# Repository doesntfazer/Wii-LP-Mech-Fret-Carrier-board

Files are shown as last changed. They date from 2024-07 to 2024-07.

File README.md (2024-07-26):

# Wii-LP-Mech-Fret-Carrier-board
A Wii Les Paul Mech fret PCB for the Frets, and the carrier board. These should be drop in replacements for the fret board and carrier board. Carrier board uses an RP2040 zero.

Frets use Choc V1 switches. I recommend using the pro reds or reds if you want to use the bracket.

Cherry MX switches for the strum. You can use whatever switches you want, But I would recommend using Box switches of some kind that are pretty heavy.

[Get the guitar configurator software here](https://github.com/Santroller/Santroller/releases/tag/v10.1.153)

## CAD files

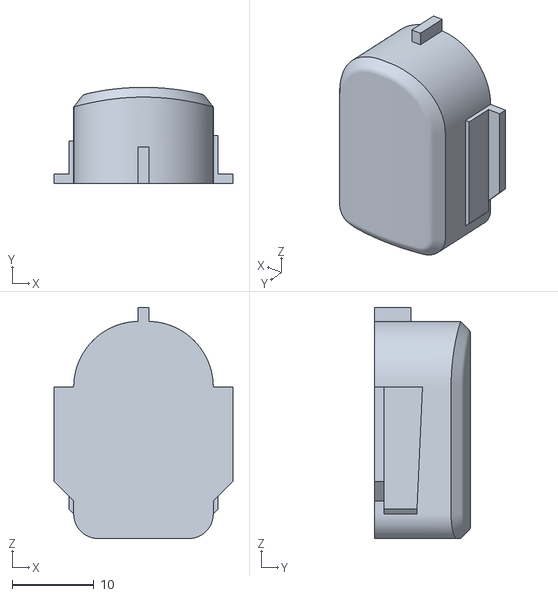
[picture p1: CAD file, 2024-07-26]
3d/Button.stl
21.9 x 11.8 x 28.3

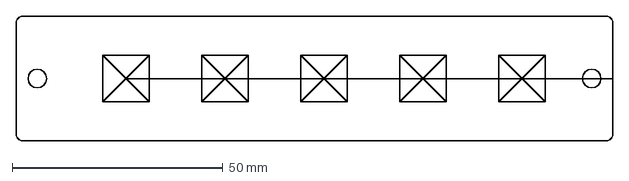
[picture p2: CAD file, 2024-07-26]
DXF/Fret.dxf
141.5 x 29.5 mm

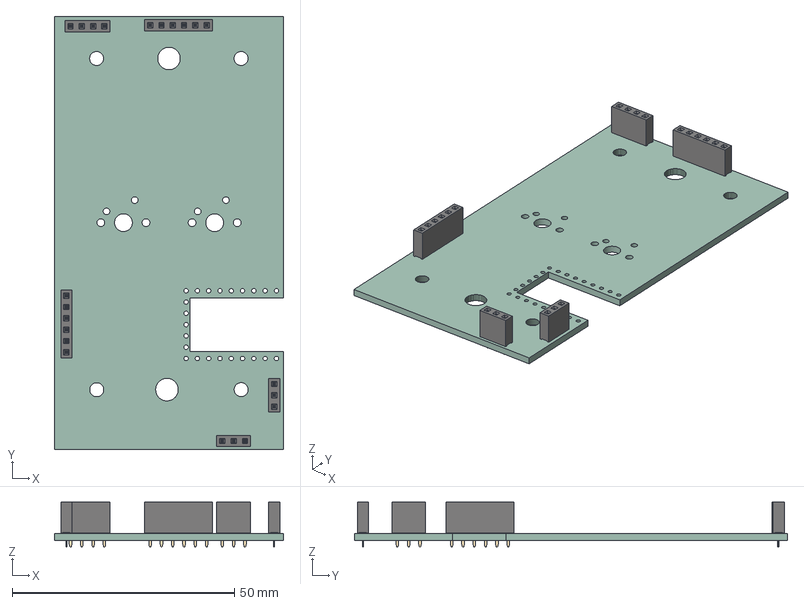
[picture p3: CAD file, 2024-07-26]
strum-kicad/strum/strum.step
51.5 x 97.5 x 10.1 mm
PCB

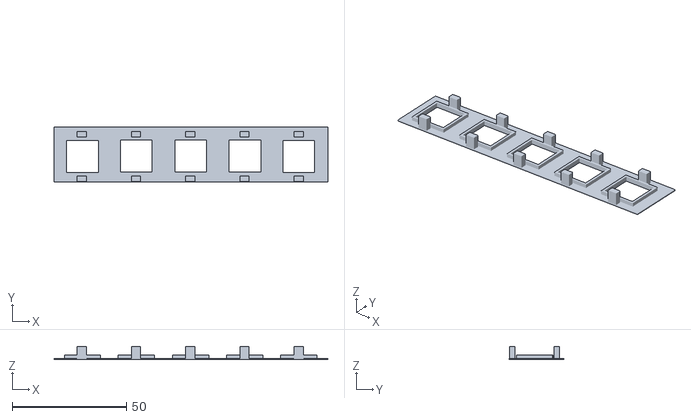
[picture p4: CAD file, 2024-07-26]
3d/Fret_bracket.stl
120.0 x 24.0 x 5.73

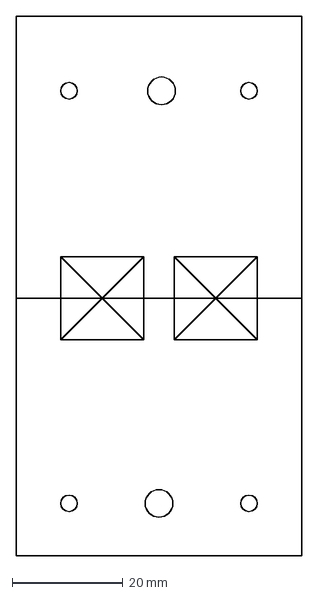
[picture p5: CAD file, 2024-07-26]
DXF/strum.dxf
51.5 x 97.5 mm

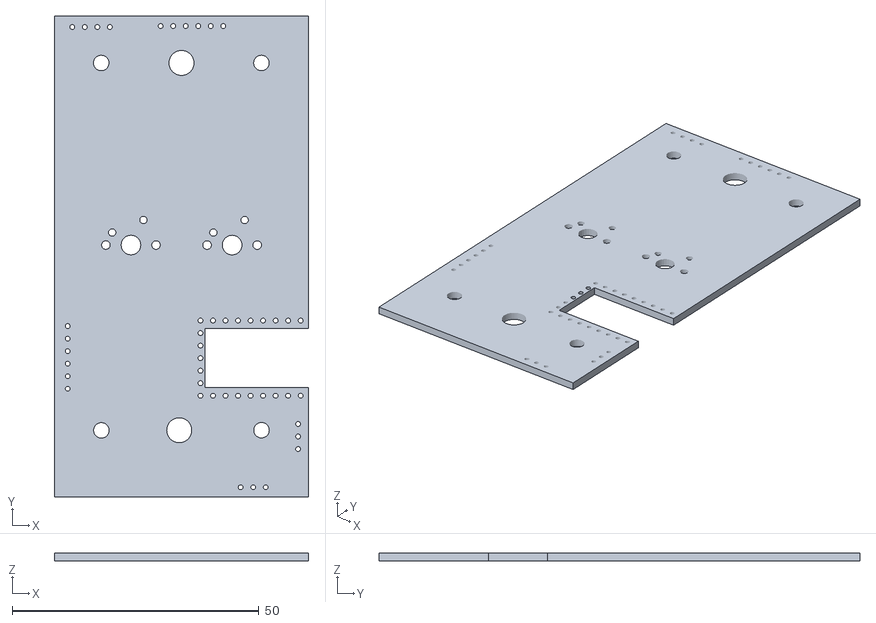
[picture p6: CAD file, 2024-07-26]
strum-kicad/strum/carrier board.stl
51.5 x 97.5 x 1.60

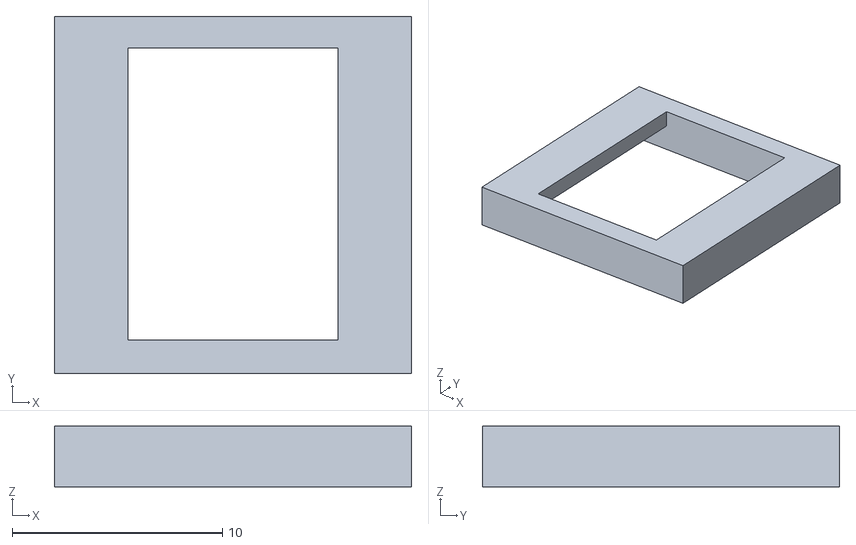
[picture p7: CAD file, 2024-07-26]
3d/switch cap.stl
17.0 x 17.0 x 2.90

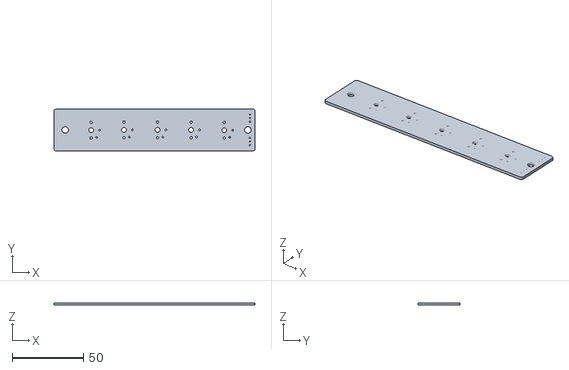
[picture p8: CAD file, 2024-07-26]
strum-kicad/strum/test.stl
141.5 x 29.5 x 1.60

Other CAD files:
strum-kicad/strum/Body1.stl
3d/fret v3.f3d

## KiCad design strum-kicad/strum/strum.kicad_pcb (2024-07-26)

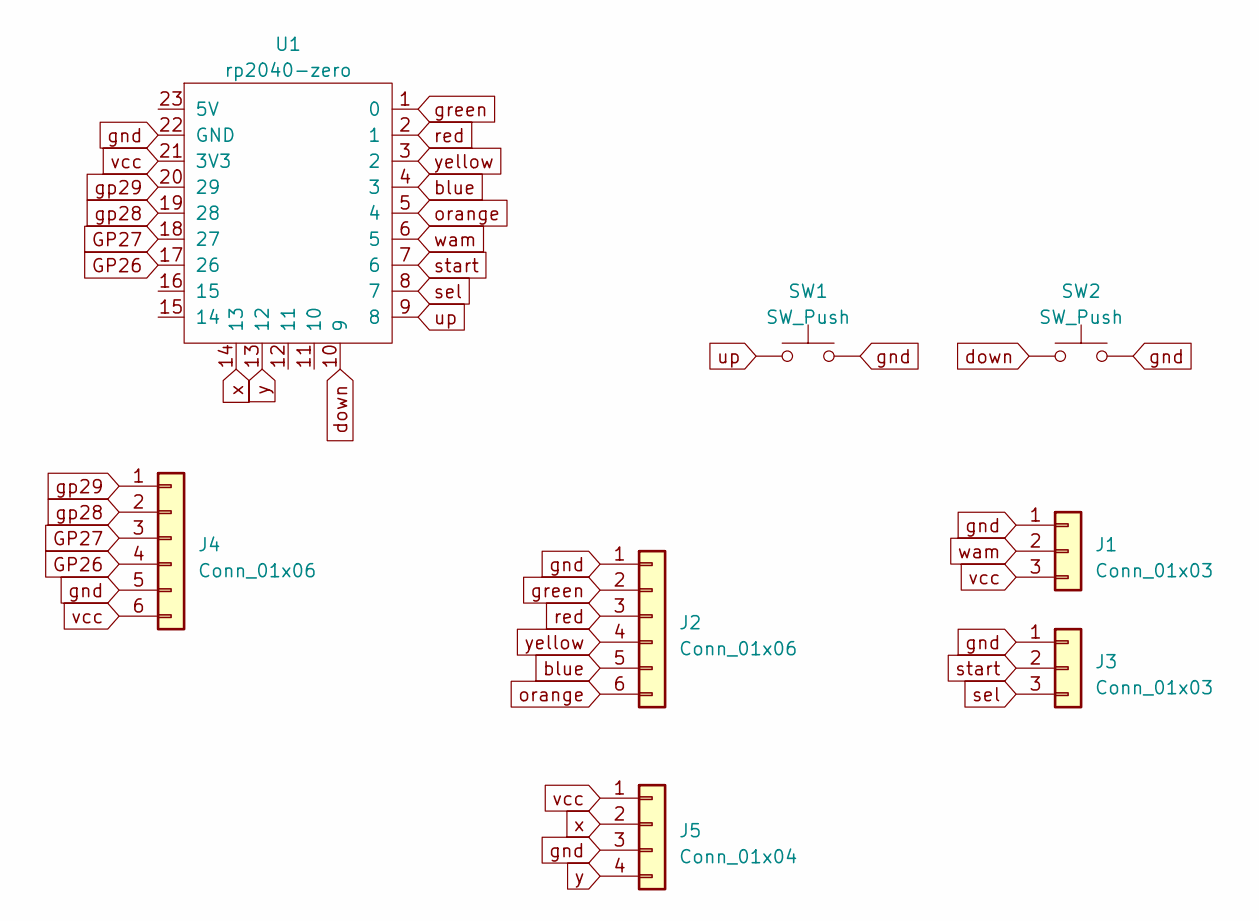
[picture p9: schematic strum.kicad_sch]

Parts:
J1, J3: Conn_01x03; PinSocket_1x03_P2.54mm_Vertical
J2, J4: Conn_01x06; PinSocket_1x06_P2.54mm_Vertical
J5: Conn_01x04; PinSocket_1x04_P2.54mm_Vertical
SW1, SW2: SW_Push; SW_Cherry_MX_PCB
U1: rp2040-zero; rp2040-zero-tht

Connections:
GP26: J4.4, U1.17 (26)
GP27: J4.3, U1.18 (27)
blue: J2.5, U1.4 (3)
down: SW2.1, U1.10 (9)
gnd: J1.1, J2.1, J3.1, J4.5, J5.3, SW1.2, SW2.2, U1.22 (GND)
gp28: J4.2, U1.19 (28)
gp29: J4.1, U1.20 (29)
green: J2.2, U1.1 (0)
orange: J2.6, U1.5 (4)
red: J2.3, U1.2 (1)
sel: J3.3, U1.8 (7)
start: J3.2, U1.7 (6)
up: SW1.1, U1.9 (8)
vcc: J1.3, J4.6, J5.1, U1.21 (3V3)
wam: J1.2, U1.6 (5)
x: J5.2, U1.14 (13)
y: J5.4, U1.13 (12)
yellow: J2.4, U1.3 (2)

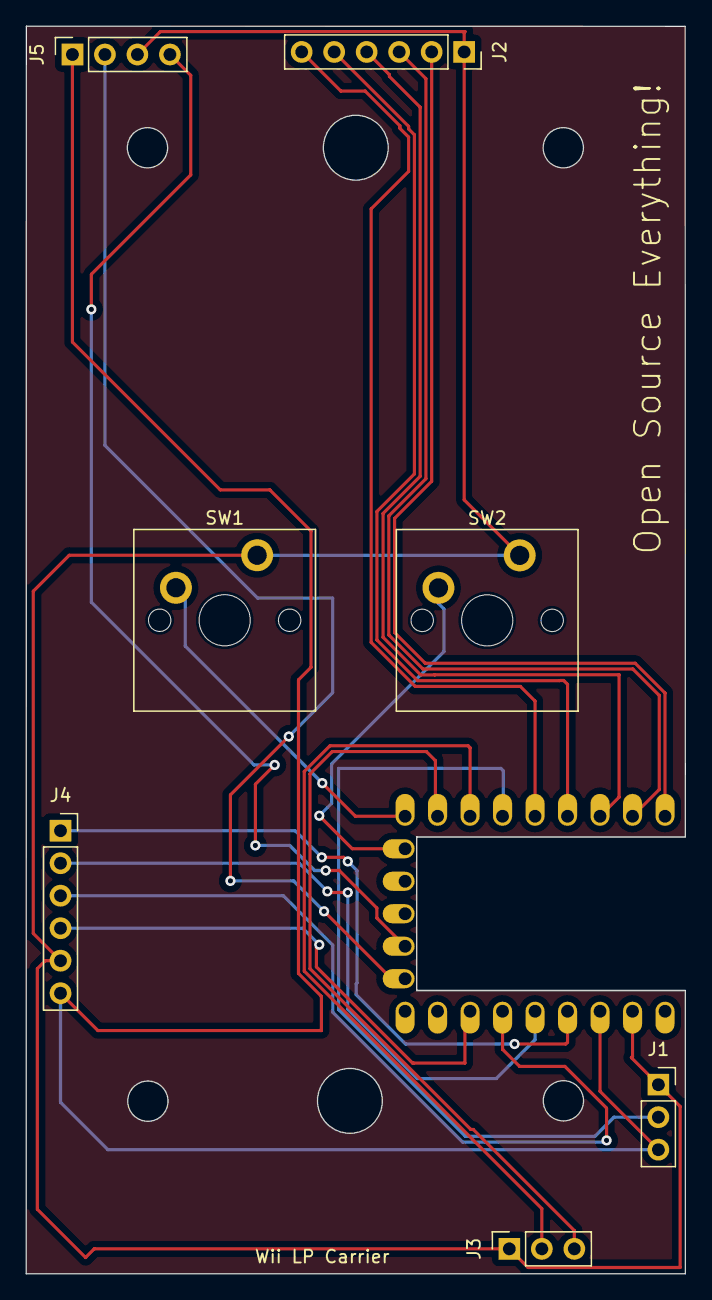
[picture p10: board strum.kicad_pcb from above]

Board: 2 copper layers, 51.5 x 97.5 mm, 8 parts (1 on the bottom side), 18 nets.

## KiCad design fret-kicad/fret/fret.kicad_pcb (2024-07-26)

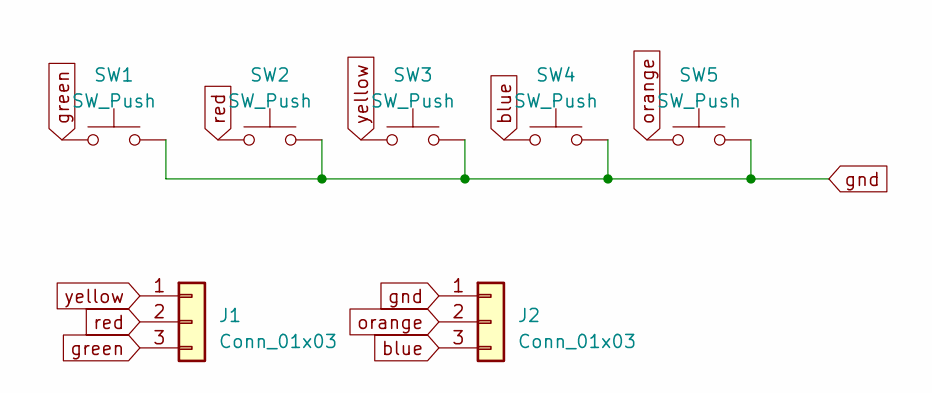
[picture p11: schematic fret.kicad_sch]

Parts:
J1, J2: Conn_01x03; PinSocket_1x03_P2.54mm_Vertical
SW1, SW2, SW3, SW4, SW5: SW_Push; Kailh-PG1350-1u-NoLED

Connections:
blue: J2.3, SW4.1
gnd: J2.1, SW1.2, SW2.2, SW3.2, SW4.2, SW5.2
green: J1.3, SW1.1
orange: J2.2, SW5.1
red: J1.2, SW2.1
yellow: J1.1, SW3.1

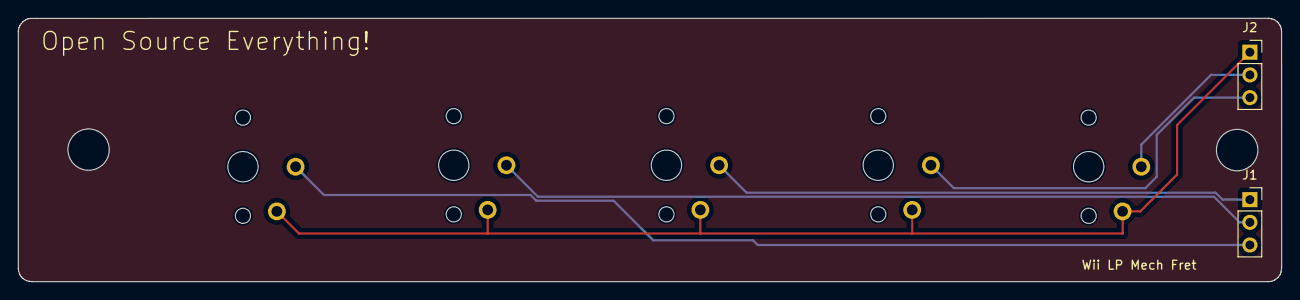
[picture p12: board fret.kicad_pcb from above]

Board: 2 copper layers, 141.5 x 29.5 mm, 7 parts (0 on the bottom side), 6 nets.

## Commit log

2024-07-26 3d Files - Fret Bracket, Fret buttons
    [Button.stl, bracket.stl, fret v3.f3d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]
2024-07-26 Dxf files
    [Fret.dxf, strum.dxf]
2024-07-26 Kicad files for fret board
    [fret-B_Cu.gbr, fret-B_Mask.gbr, fret-B_Paste.gbr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]
2024-07-26 Carrier board and strum
    [Body1.stl, carrier board.stl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]
